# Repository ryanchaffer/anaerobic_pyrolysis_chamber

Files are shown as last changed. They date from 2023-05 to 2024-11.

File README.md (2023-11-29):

# Anaerobic Pyrolysis Chamber (APC)
The anaerobic pyrolysis chamber (APC) was devised to provide a well-defined gas atmosphere (typically inert) in a controlled elevated temperature environment. The APC is comprised of a chamber machined from stainless steel that may be sealed and placed inside a muffle furnace. The initial purpose of the APC was to force ligno-cellulosic samples through thermal degradation so that additional tests could be conducted to characterize the thermo-physical properties of the residual mass. The chamber was designed to be sealed and constantly purged with the desired gas. In the case of the ligno-cellulosic samples, the purge gas was selected as nitrogen to prevent oxidation of the produced char or any spontatneous combustion of the produced effluent. 

This repository is divided into two directories: 01_Design and 02_Controls. 01_Design includes editable geometry files and schematics in PDF form and 02_Controls includes the programs written to control the APC and log data.



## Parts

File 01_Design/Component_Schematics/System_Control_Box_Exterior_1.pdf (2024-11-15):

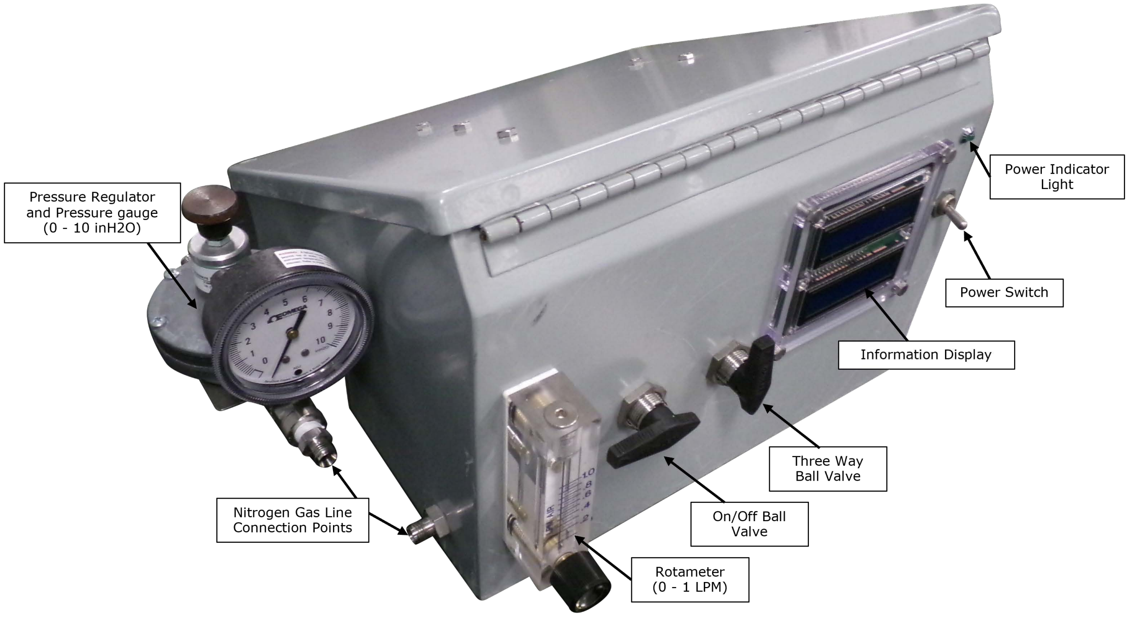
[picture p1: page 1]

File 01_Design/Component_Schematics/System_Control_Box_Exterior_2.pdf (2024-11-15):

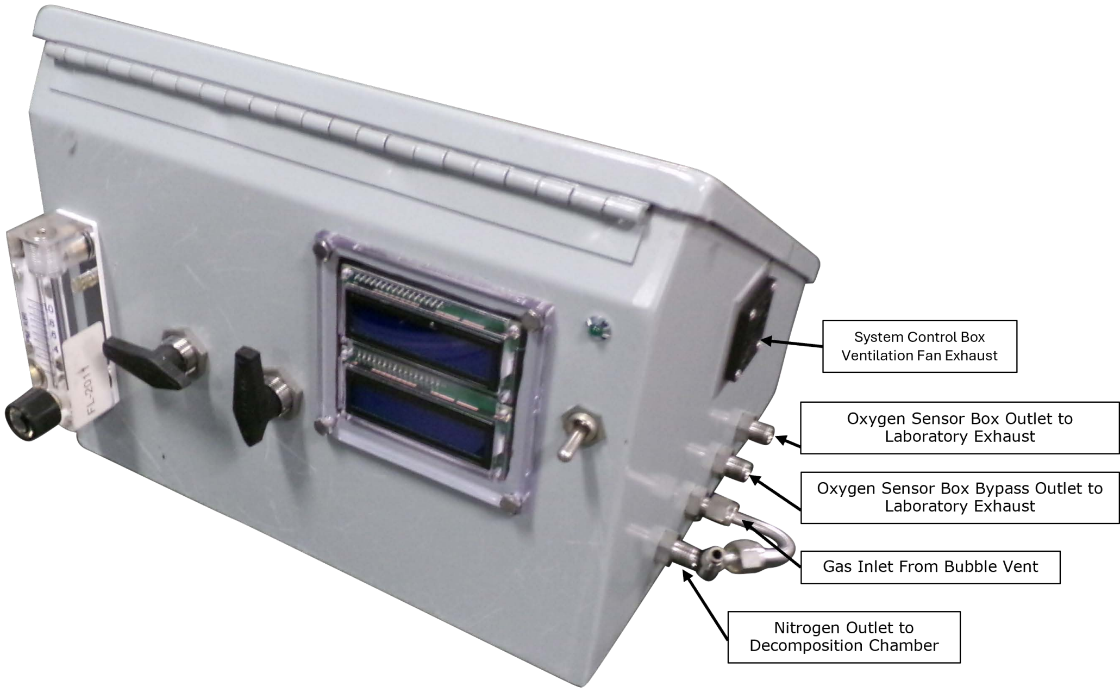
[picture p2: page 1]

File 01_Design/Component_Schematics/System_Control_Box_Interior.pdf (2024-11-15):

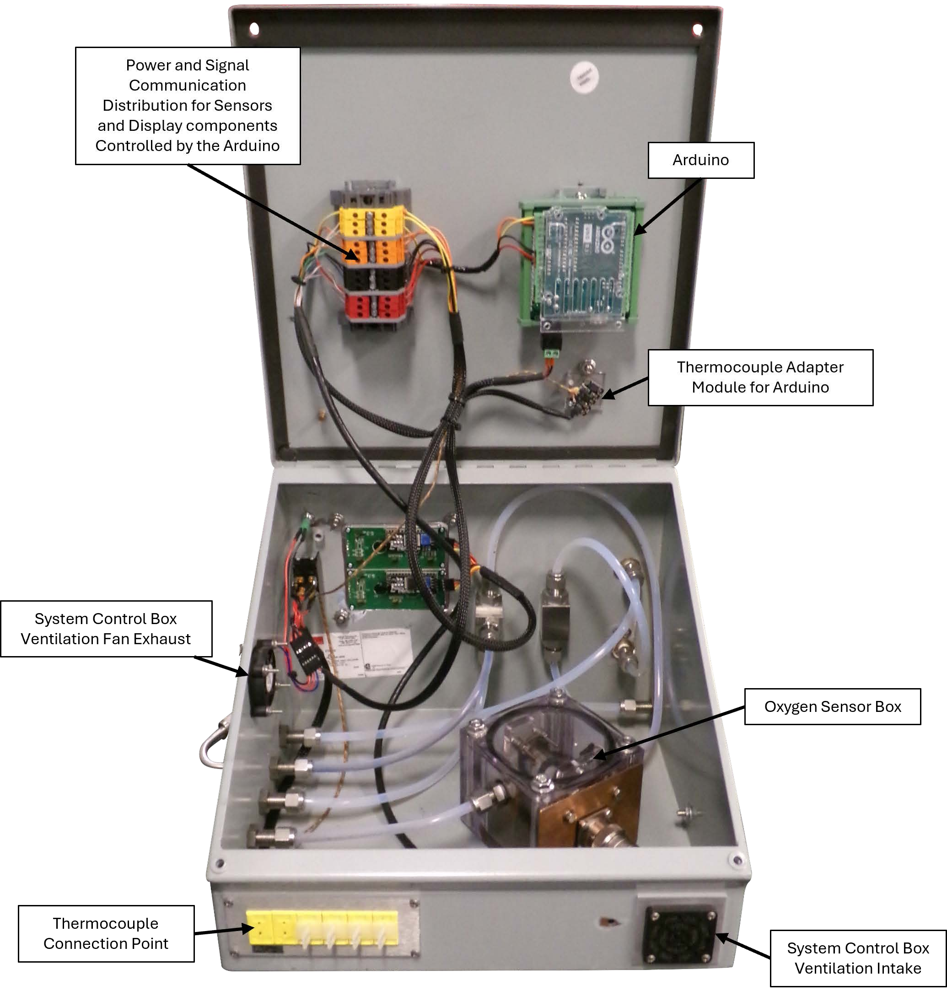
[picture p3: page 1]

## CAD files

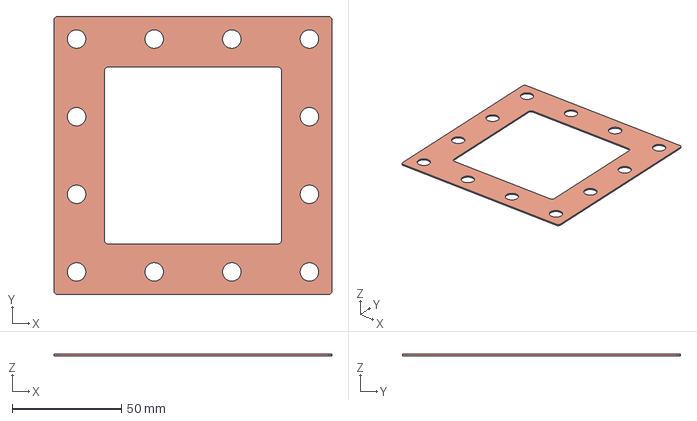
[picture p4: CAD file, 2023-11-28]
01_Design/Component_Geometry/Chamber_Gasket.stp
127.0 x 127.0 x 0.813 mm

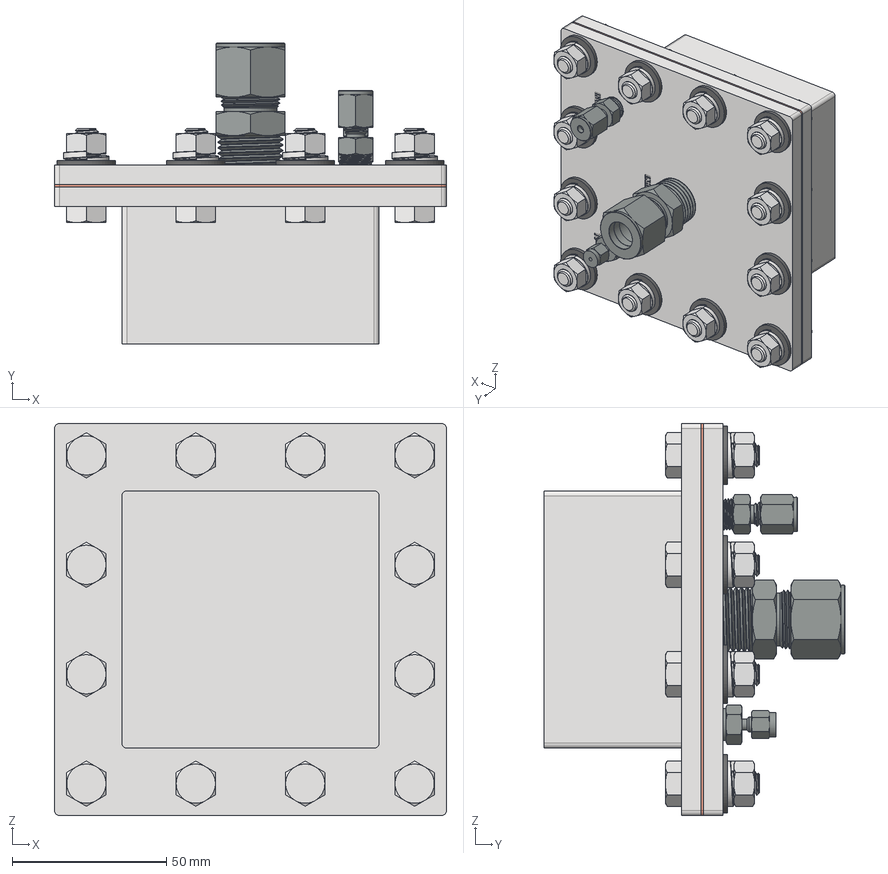
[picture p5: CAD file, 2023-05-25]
01_Design/Component_Geometry/Decomposition_Chamber.stp
127.0 x 97.5 x 127.0 mm
Chamber Base
Lid
Chamber_Gasket_Final
94895A115_High-Strength Steel Hex Nut x 12
92240A583_18-8 Stainless Steel Hex Head Screw x 12
92146A622_18-8 Stainless Steel Split Lock Washer x 12
96765A145_Black-Oxide 18-8 Stainless Steel Washer x 12
5182K135
SS-100-1-2BT
5182K804

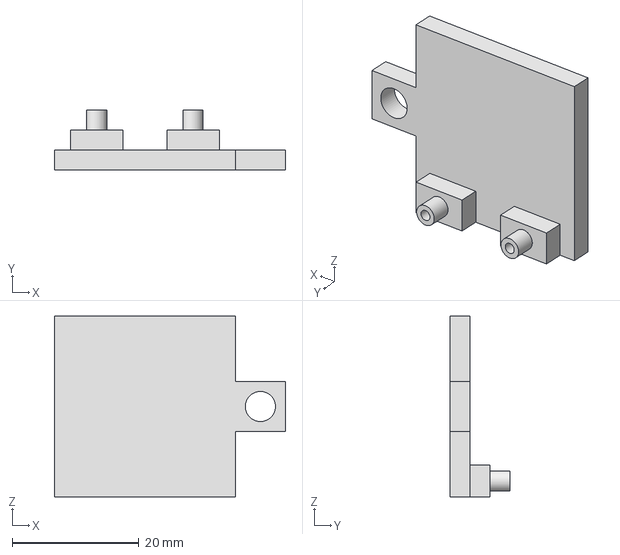
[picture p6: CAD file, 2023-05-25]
01_Design/Component_Geometry/Thermocouple_Amplifier_Mounting_Bracket.stp
36.5 x 9.52 x 28.6 mm

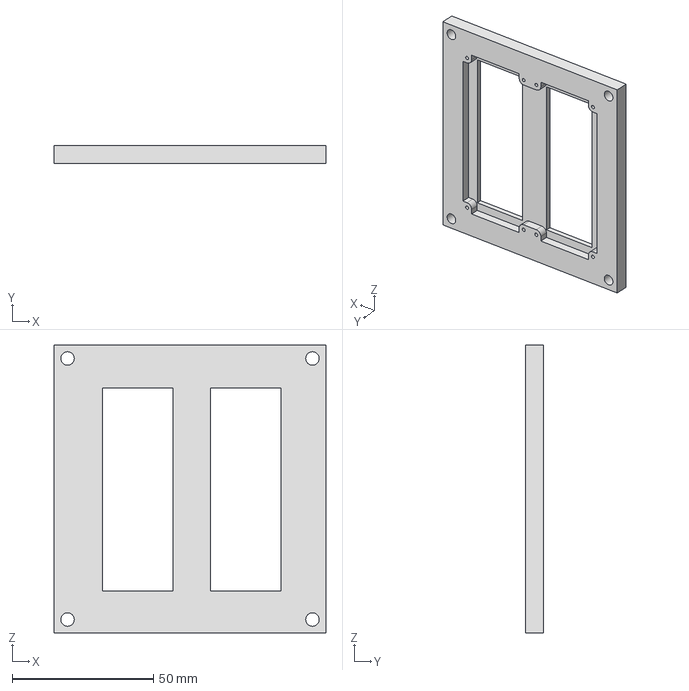
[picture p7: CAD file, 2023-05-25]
01_Design/Component_Geometry/LCD_Display_Mounting.stp
96.2 x 6.35 x 102.0 mm

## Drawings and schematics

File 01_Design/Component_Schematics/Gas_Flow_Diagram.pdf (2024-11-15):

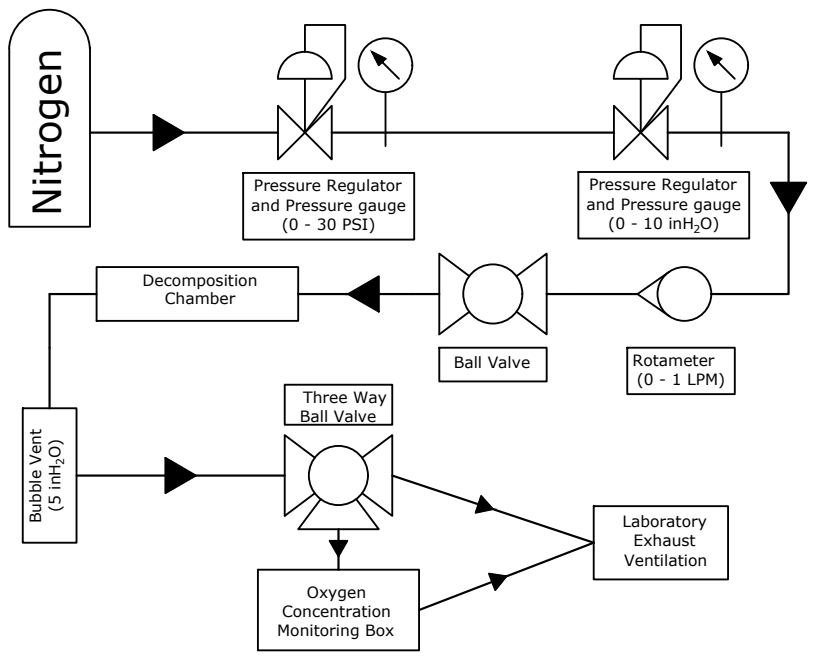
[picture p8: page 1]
Bubble Vent

Nitrogen Pressure Regulator and Pressure gauge (0 - 30 PSI) Pressure Regulator and Pressure gauge (0 - 10 inH2O) Rotameter (0 - 1 LPM) Ball Valve Decomposition Chamber

(5 inH2O) Three Way Ball Valve Oxygen Concentration Monitoring Box Laboratory Exhaust Ventilation

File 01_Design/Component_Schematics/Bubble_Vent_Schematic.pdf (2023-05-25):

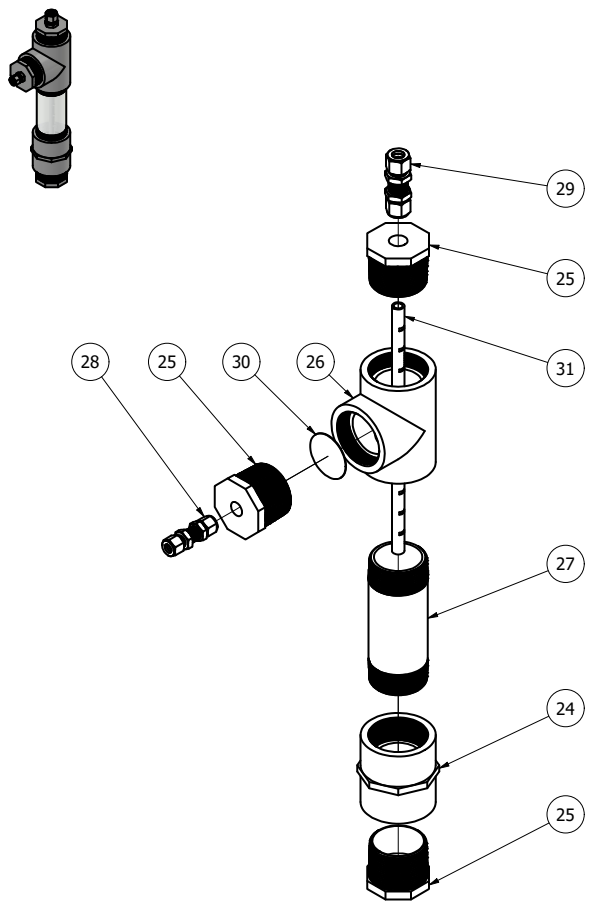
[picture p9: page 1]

PARTS LIST

ITEM | DESCRIPTION | PART NUMBER | QTY
24 | Straight Connector, 2 Inch NPT Female | 4596K57 | 1
25 | Plug, 2 Inch NPT Male | 4596K78 | 3
26 | Tee Connector, 2 Inch NPT Female | 4596K37 | 1
27 | Pipe Nipple, 6 inches Long, 2 Inch NPT | 4677T45 | 1
28 | 3/8" Tube OD Through-Wall Fitting | 5182K377 | 1
29 | 1/2" Tube OD Through-Wall Fitting | 5182K378 | 1
30 | Wire Cloth Discs, 30 x 30 Mesh Size | 9317T147 | 1
31 | 1/2" OD, Cut To 12 Inches | 89785K845 | 1

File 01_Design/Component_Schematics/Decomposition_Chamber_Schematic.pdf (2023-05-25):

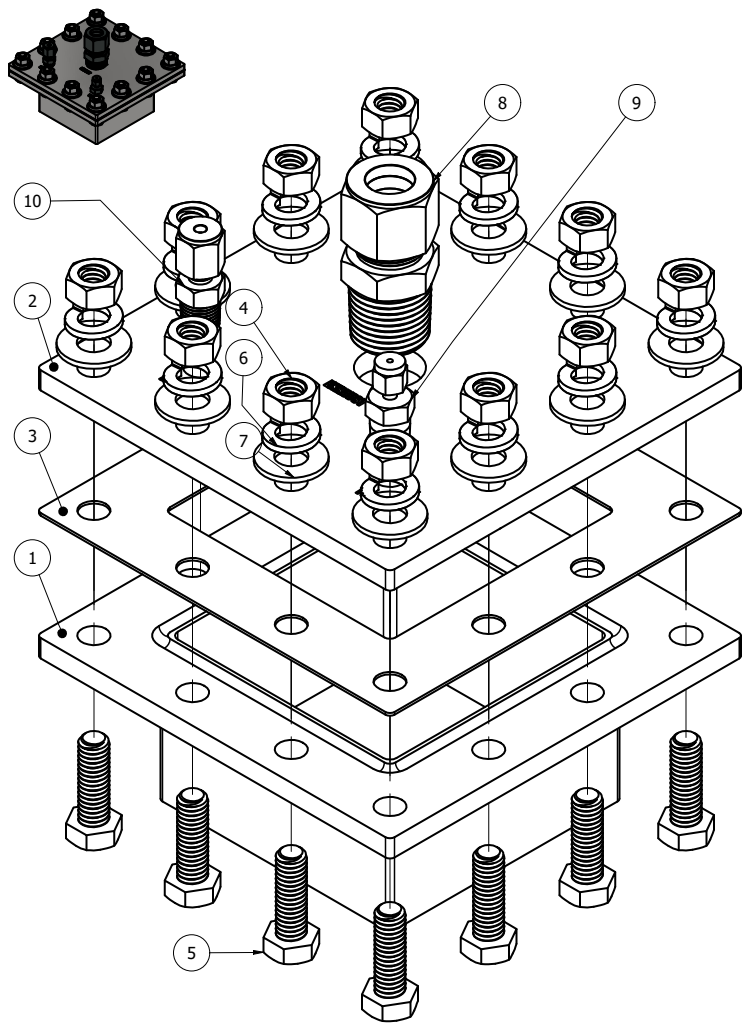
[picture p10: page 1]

PARTS LIST
ITEM | DESCRIPTION | PART NUMBER | QTY
1 | Chamber Base | N/A | 1
2 | Chanber Lid | N/A | 1
3 | Copper Gasket, Cut from Sheet Stock With In House CNC Router | 2545T21 | 1
4 | High-Strength Steel Hex Nut, Grade 8, Black-Oxide, 5/16"-18 Thread Size | 94895A115 | 12
5 | 18-8 Stainless Steel Hex Head Screw, 5/16"-18 Thread Size, 1" Long | 92240A583 | 12
6 | 18-8 Stainless Steel Split Lock Washer, Black Oxide, 5/16" Screw Size | 92146A622 | 12
7 | Black-Oxide 18-8 Stainless Steel Washer, 5/16" Screw Size | 96765A145 | 12
8 | 1/2" Tube OD x 1/2" NPT Male | 5182K135 | 1
9 | 1/16" Tube OD x 1/8" NPT Male | SS-100-1-2BT | 1
10 | 1/8" Tube OD x 1/8" NPT Male | 5182K804 | 1

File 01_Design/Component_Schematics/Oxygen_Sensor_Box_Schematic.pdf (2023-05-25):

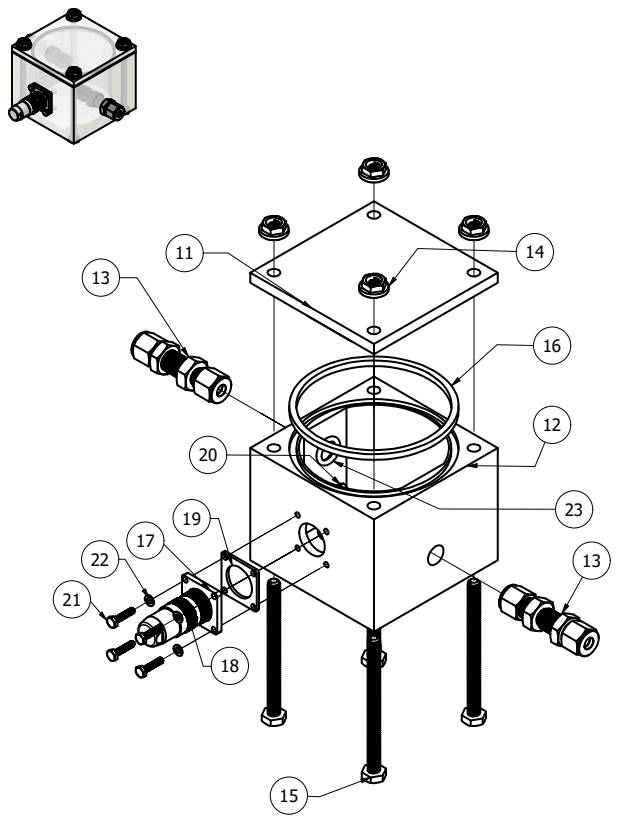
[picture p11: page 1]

PARTS LIST

ITEM | DESCRIPTION | PART NUMBER | QTY
11 | Oxygen Sensor Box Lid | N/A | 1
12 | Oxygen Sensor Box Base | N/A | 1
13 | 1/4" Tube OD Through-Wall Fitting | 5182K375 | 2
14 | 316 Stainless Steel Flange Nuts, 1/4"-20 Thread Size | 90389A114 | 4
15 | 18-8 Stainless Steel Hex Head Screw, 1/4"-20 Thread Size, 3-1/4" Long | 92800A362 | 4
16 | Square-Profile Oil-Resistant Buna-N O-Ring, 1/8" Fractional Width, Dash Number 235 | 4061T257 | 1
17 | 8-pin electrical receptical | RT00128PKNH03-K | 1
18 | 8-pin electrical plug | RT06128SNH03SS-K | 1
19 | Plug Gasket | RTFD12B | 1
20 | 18-8 Stainless Steel Hex Nut, M3 x 0.5 mm Thread Size | 91828A211 | 4
21 | 18-8 Stainless Steel Hex Head Screw, M3 x 0.5 mm Thread Size, 14 mm Long | 92800A537 | 4
22 | 18-8 Stainless Steel Washer, M3 Screw Size | 98689A112 | 8
23 | Oil-Resistant Buna-N O-Ring | 9452K23 | 2

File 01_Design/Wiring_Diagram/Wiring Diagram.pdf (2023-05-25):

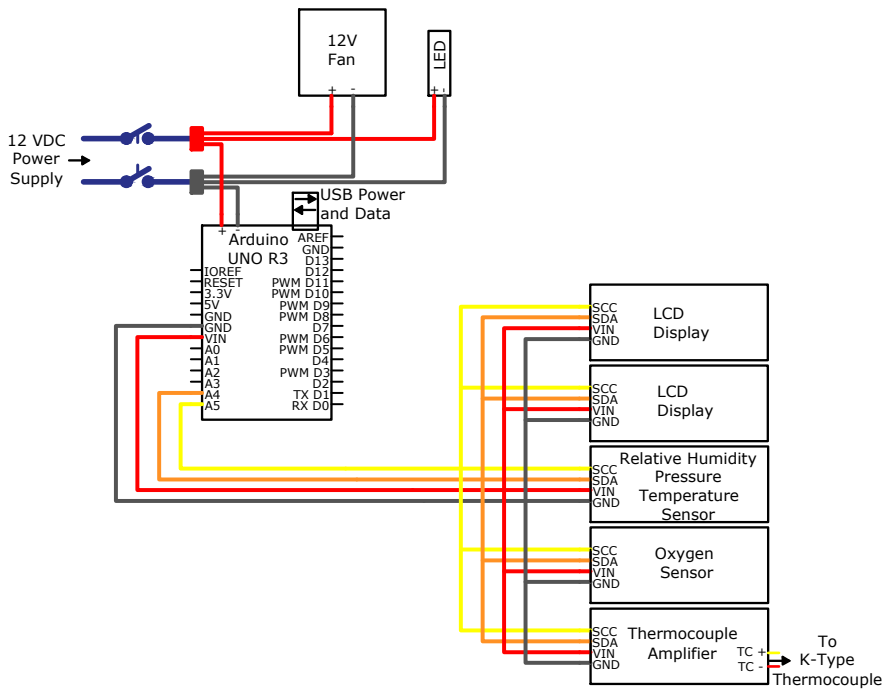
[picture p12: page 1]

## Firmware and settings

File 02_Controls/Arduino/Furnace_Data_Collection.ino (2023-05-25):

#include <Adafruit_MCP9601.h> //Furnace Temperture Module
#include <Adafruit_BME280.h>  //O2 Box RH, Pressure, and Temperature Module
#include <DFRobot_OxygenSensor.h> //O2 sensor Module
#include <Wire.h>
#include <LiquidCrystal_I2C.h> //Display Module




#define COLLECT_NUMBER    10             // collect number, the collection range is 1-100.
#define Oxygen_IICAddress ADDRESS_3

#define Furnace_Temperature (0x67)
Adafruit_MCP9601 mcp;  

DFRobot_OxygenSensor Oxygen;
LiquidCrystal_I2C lcd(0x26, 16, 2); // set the LCD address to 0x27 for a 16 chars and 2 line display
LiquidCrystal_I2C lcd2(0x27, 16, 2); // set the LCD address to 0x27 for a 16 chars and 2 line display
Adafruit_BME280 bme;

bool label =  true;
void setup()
{

  Serial.begin(9600);
  while (!Oxygen.begin(Oxygen_IICAddress)) {
//    Serial.println("I2c device number error !");
    delay(1000);
  }
//  Serial.println("I2c connect success !");

// Furnace Temperture Sensor
  if (! mcp.begin(Furnace_Temperature)) {
//        Serial.println("Sensor not found. Check wiring!");
        while (1);
    }
//  Serial.println("Found MCP9601!");

  mcp.setADCresolution(MCP9600_ADCRESOLUTION_18);
//  Serial.print("ADC resolution set to ");
  switch (mcp.getADCresolution()) {
    case MCP9600_ADCRESOLUTION_18:   ; break;
    case MCP9600_ADCRESOLUTION_16:   ; break;
    case MCP9600_ADCRESOLUTION_14:   ; break;
    case MCP9600_ADCRESOLUTION_12:   ; break;
  }
//  Serial.println(" bits");

  mcp.setThermocoupleType(MCP9600_TYPE_K);
//  Serial.print("Thermocouple type set to ");
  switch (mcp.getThermocoupleType()) {
    case MCP9600_TYPE_K:  ; break;
    case MCP9600_TYPE_J: ; break;
    case MCP9600_TYPE_T:  ; break;
    case MCP9600_TYPE_N:  ; break;
    case MCP9600_TYPE_S:  ; break;
    case MCP9600_TYPE_E:  ; break;
    case MCP9600_TYPE_B:  ; break;
    case MCP9600_TYPE_R:  ; break;
  }
//  Serial.println(" type");

  mcp.setFilterCoefficient(3);
//  Serial.print("Filter coefficient value set to: ");
//  Serial.println(mcp.getFilterCoefficient());

  


// default settings for Relative Humidity Sensor
  unsigned status;
  status = bme.begin();


  lcd.init();                      // initialize the lcd
  lcd2.init();
  
  lcd.backlight();
  lcd2.backlight();
  
  // Print Start Up Message
    lcd.setCursor(5, 0);
    lcd.print("Welcome");
    lcd2.setCursor(6, 0);
    lcd2.print("FSRI");
    delay(10000);
 
  lcd.clear();                      // clear the lcd after Start Up Message
  lcd2.clear();

  // lcd 1 display parameters
  lcd.setCursor(0, 0);
  lcd.print("O2:");
  lcd.setCursor(10, 0);
  lcd.print("RH: ");
    lcd.setCursor(4, 1);
  lcd.print("P: ");

  // lcd 2 display parameters
  lcd2.setCursor(0, 0);
  lcd2.print("TG: ");
  lcd2.setCursor(0, 1);
  lcd2.print("TC: ");


  
}


void loop()
{



  
  // Temperature inside chamber display

  uint8_t status = mcp.getStatus();
//  Serial.print("MCP Status: 0x"); 
//  Serial.print(status, HEX);  
//  Serial.print(": ");
  
  
   double c = (mcp.readThermocouple());;
   lcd2.setCursor(4, 1);
   
   if (status & MCP9601_STATUS_OPENCIRCUIT) { 
    lcd2.print(c);
    lcd2.print("*");    
   }
   else if (status & MCP9601_STATUS_SHORTCIRCUIT) { 
   lcd2.print(c);
   lcd2.print("**");
   }
   else
   {
     lcd2.print(c);
     lcd2.print("      ");
    
   }
   
  // Oxygen Display
  float oxygenData = Oxygen.getOxygenData(COLLECT_NUMBER);
  lcd.setCursor(4, 0);
  lcd.print(oxygenData);


  // Relative Humidity Display
  lcd.setCursor(14, 0);
  float RH = (bme.readHumidity());
  String RH_Out = String(RH, 0); //Makes the float a string with 0 decimal places
  lcd.print(RH_Out);

  // Pressure Display
  lcd.setCursor(6, 1);
  float P = (bme.readPressure() / 1000.0F);
  String P_Out = String(P, 3); //Pressure in kPa
  lcd.print(P_Out);

  // Temperature of gas at Oxygen Sensor Display
  lcd2.setCursor(4, 0);
  float T = (bme.readTemperature());
  String T_Out = String(T, 2);
  lcd2.print(T_Out);


// Set up Serial Monitor to log data to .CSV

// 
  while(label){// runs once, sets up column headers
    Serial.print("Chamber Temperature [°C]");
    Serial.print(",");
    Serial.print("Oxygen Concentration [%]");
    Serial.print(",");
    Serial.print("Relative Humidity [%]");
    Serial.print(",");
    Serial.print("Pressure [kPa]");
    Serial.print(",");
    Serial.print("Oxygen Box Temperature [°C]");
    Serial.println(",");
    
    label=false;
  }

// Print the collected data out on the same line, then repeat every second 
  Serial.print(c);
  Serial.print(",");
  Serial.print(oxygenData);
  Serial.print(",");
  Serial.print(RH);
  Serial.print(",");
  Serial.print(P_Out);
  Serial.print(",");
  Serial.print(T);
  Serial.println(",");
 
  
  
  delay(1000);

 
}

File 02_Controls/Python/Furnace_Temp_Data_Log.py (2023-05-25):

# Furnace_Temp_Data_Log.py
#	by: R.Chaffer
# ***************************** Run Notes ***************************** #
# - Data Log file will save to the same folder directory as python script.
#
#
#
# ********************************************************************* #

# --------------- #
# Import Packages #
# --------------- #
import serial 
import datetime

# Specify the port in use for arduino communication and the baud rate of the arduino's serial communication
arduino_port = "COM5"
baud = 9600

# Define date format
ct = datetime.datetime.now()
ct = ct.strftime('%Y%m%d%H%M%S')

# Generate File name for the log. Using datetime as part of the entry allow for a unique log file name every run. 
fileName = ct + "_Chamber_Temp_Log.csv"

# Access the arduino Serial communication and create the Log file.
ser = serial.Serial(arduino_port, baud)
print("Connected to Arduino port:" + arduino_port)
file = open(fileName, "w")
print("Created file")


samples = 60000 #how many samples to collect
print_labels = False
line = 0 #start at 0 because our header is 0 (not real data)
while line <= samples:
    # When the value of line = the value of samples, the loop will end
	getData=str(ser.readline())
	data=getData.replace("b'","")
	data=data.replace(",\\r\\n'","")
	# ct stores current time
	ct = datetime.datetime.now()
	

	ct = ct.strftime("%H:%M:%S.%f")

	
	# Print the Time in the first column, then the data collected by the arduino
	printstring = ct+","+data
	print(printstring)

	file = open(fileName, "a")
	file.write(printstring + "\n") #write data with a newline
	line = line+1

# After data collection is complete, print message and close .CSV file.
print("Data collection complete!")
file.close()

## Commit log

2023-05-25 mckinnon: initial commit
    [Decomposition_Chamber.stp, LCD_Display_Mounting.stp, Thermocouple_Amplifier_Mounting_Bracket.stp]
2023-11-28 Added stp file for chamber gasket
    [Chamber_Gasket.stp]
